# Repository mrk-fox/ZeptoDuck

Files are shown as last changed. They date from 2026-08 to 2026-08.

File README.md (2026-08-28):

<div align="center">
<h1>ZeptoDuck</h1><br>
The smallest "Rubber Ducky" in the world.
<br>

 

<br>

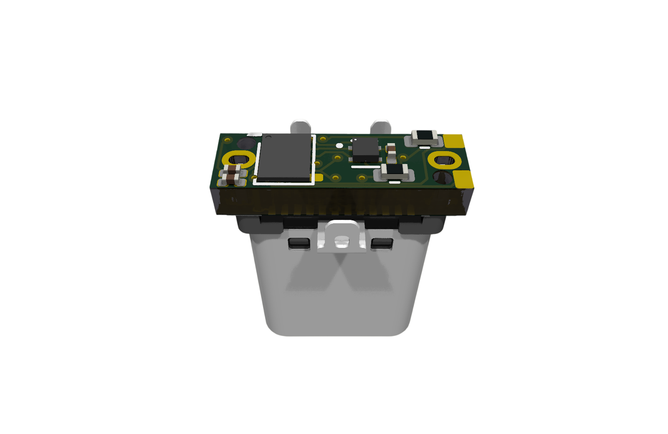
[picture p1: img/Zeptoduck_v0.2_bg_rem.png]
Flowers

</div>

# What is ZeptoDuck about?
In the world of rising digital vurneablility due to the effects of digitalization we are forced to develop tools to pentest the security structures we have developed and established over the years. One poular tool attackers use is the "Rubber Ducky". It is a broad term for a programmable HID execution device. The ZeptoDuck project, with the term "Zepto" coming from the greek word ζεπτο meaning one sextilionth is a electronics project to build such a device. The term "Zepto" was used to display the size of the ZeptoDuck being only about 10x3x15mm. This would be the world record for the smallest rubber ducky ever produced. 

# Features
ZeptoDuck covers a narrow spectre of features dur to its very specific usecase.

- ATSAMD11D14A-UUT as the main MCU
- Programmable via the SWD pads and the USB-C port with correct software.
- HID Input device capabilities.

# PCB and Schematics

The PCB itself is a minatuarized 2-Layer FR4 PCB with only a few components, most of them in very small formats.

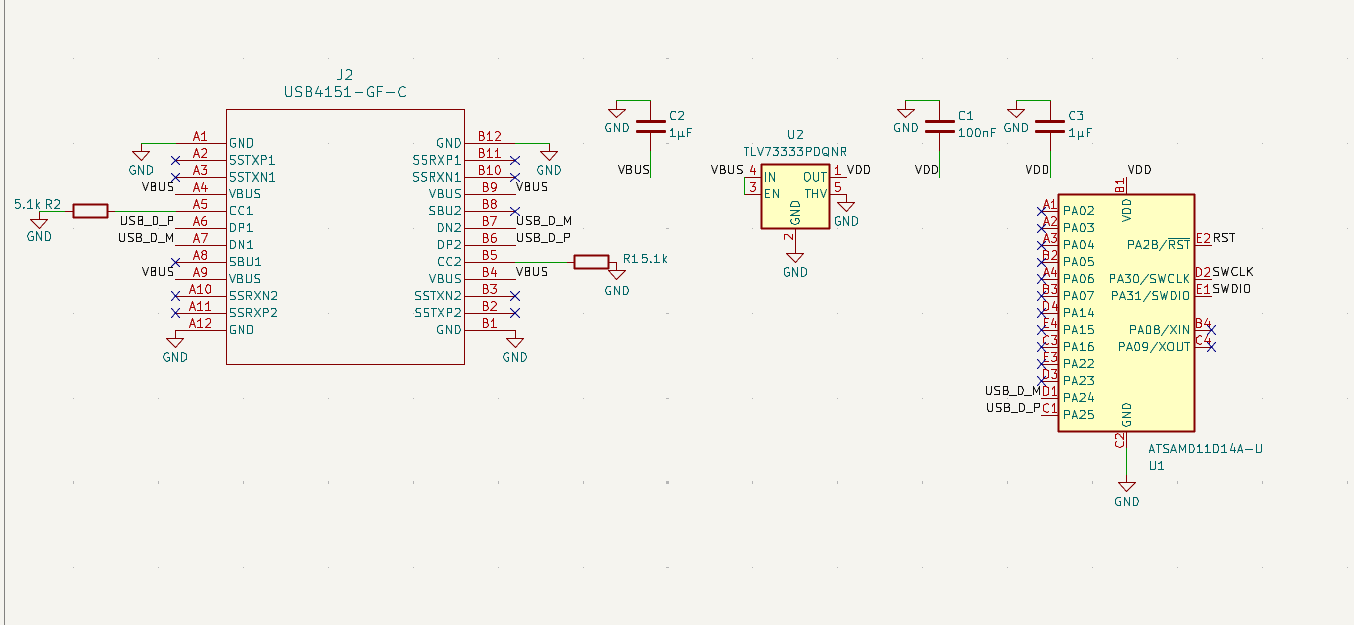
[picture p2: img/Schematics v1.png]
ZeptoDuck Schematics

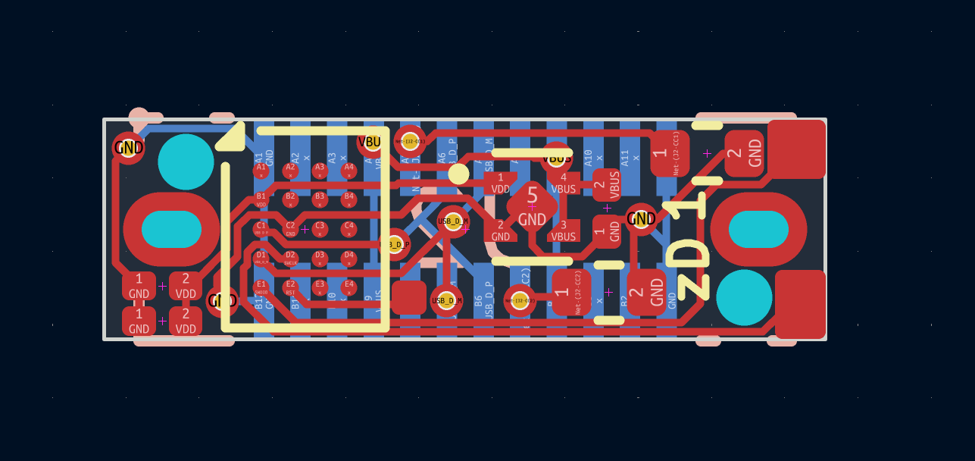
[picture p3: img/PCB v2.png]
ZeptoDuck PCB


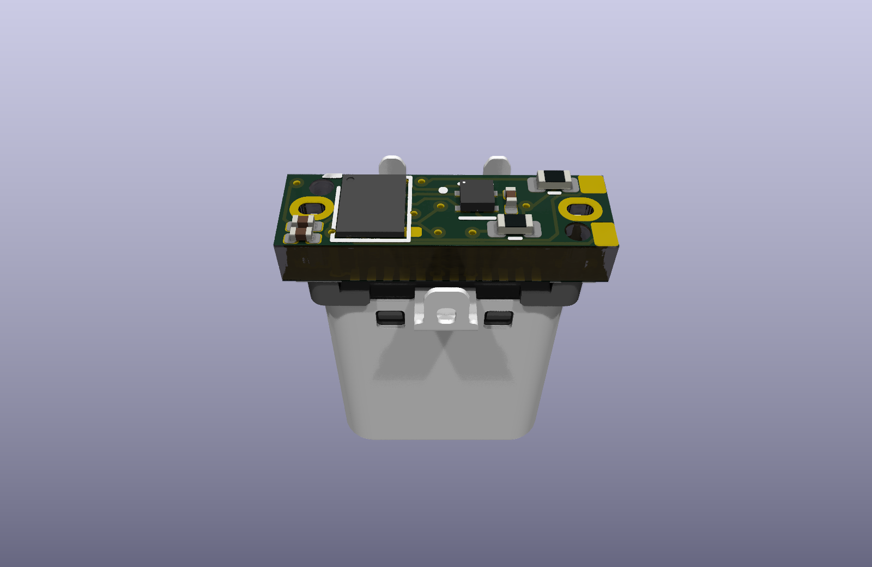
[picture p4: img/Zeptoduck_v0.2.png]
Zeptoduck Rendered

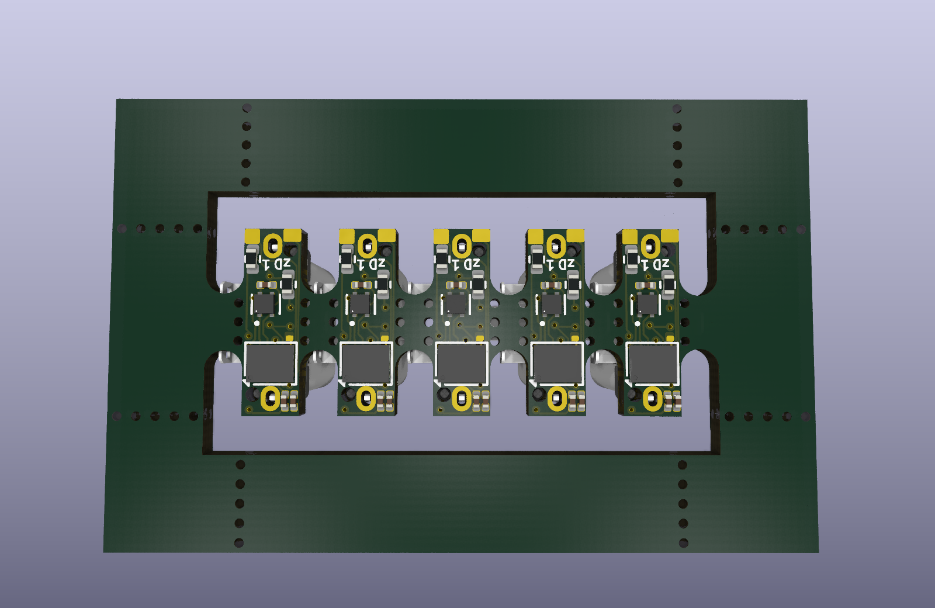
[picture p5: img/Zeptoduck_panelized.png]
Panelized ZeptoDuck Rendered


# Assembly and Flashing

1. Apply solder paste through the soldermask on all necessary components footprints
2. Place the components on the PCB
3. Use a hotplate to solder the components to the PCB
4. Cut off the additional holders for the USB-C port
5. Flip the PCB and hand-solder the USB-C port (The hard part)
6. Flash the PCB using any pogo pin assembly while applying 5V voltage through the USB-C port
7. Youre ready to hack!

# BOM

| id | Name | Qty | Price | |
|----|---|-----|---|---|
| 1  | PCB | 1 | 11.5$ | |
| 2  | ATSAMD11D14A-UUT | 10  | 16$ | |
| 3  | TLV73333PDQNR | 10  | 5$ | |
| 4  | WWE Shipping and Handling | 4 | 39$ | |
| x  | All other parts are in stock. | x | x | |
| x  | TOTAL | | 71.5$ | |

# Information for reviewers
28.08.2026: The parts are avalible via a custom agreement between me and Worldway electronics. This project required 22 hours in total to finish. Thanks for reviewing.

# Thanks
I generously thank Worldway Electronics for kindy agreeing on an MOQ relaxation. <br>
WWE Logo

Make sure to check out their website! 
worldwayelec.com

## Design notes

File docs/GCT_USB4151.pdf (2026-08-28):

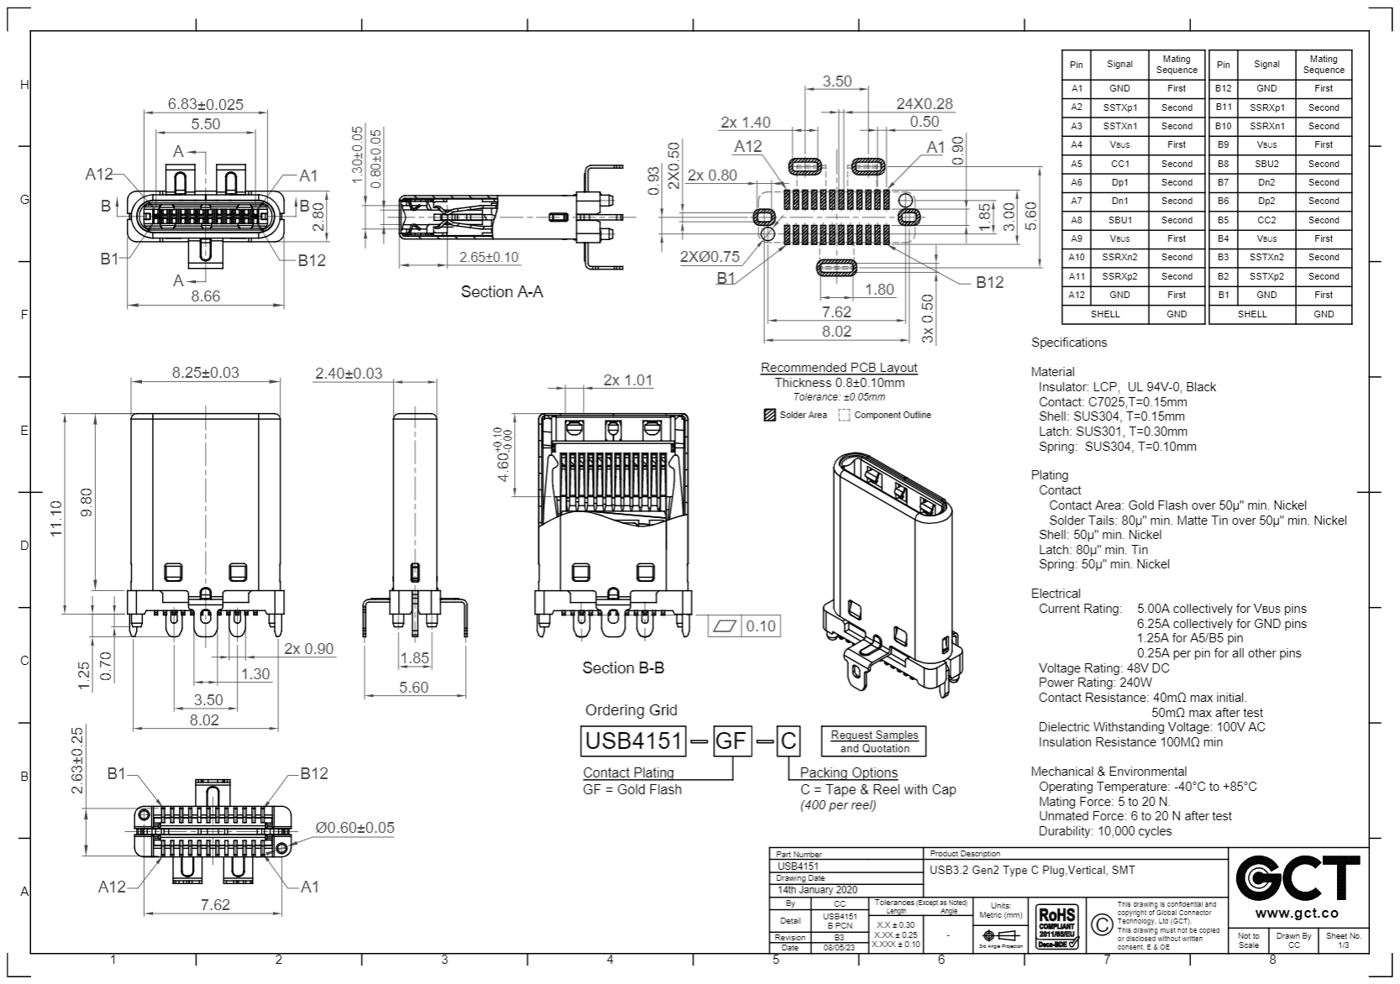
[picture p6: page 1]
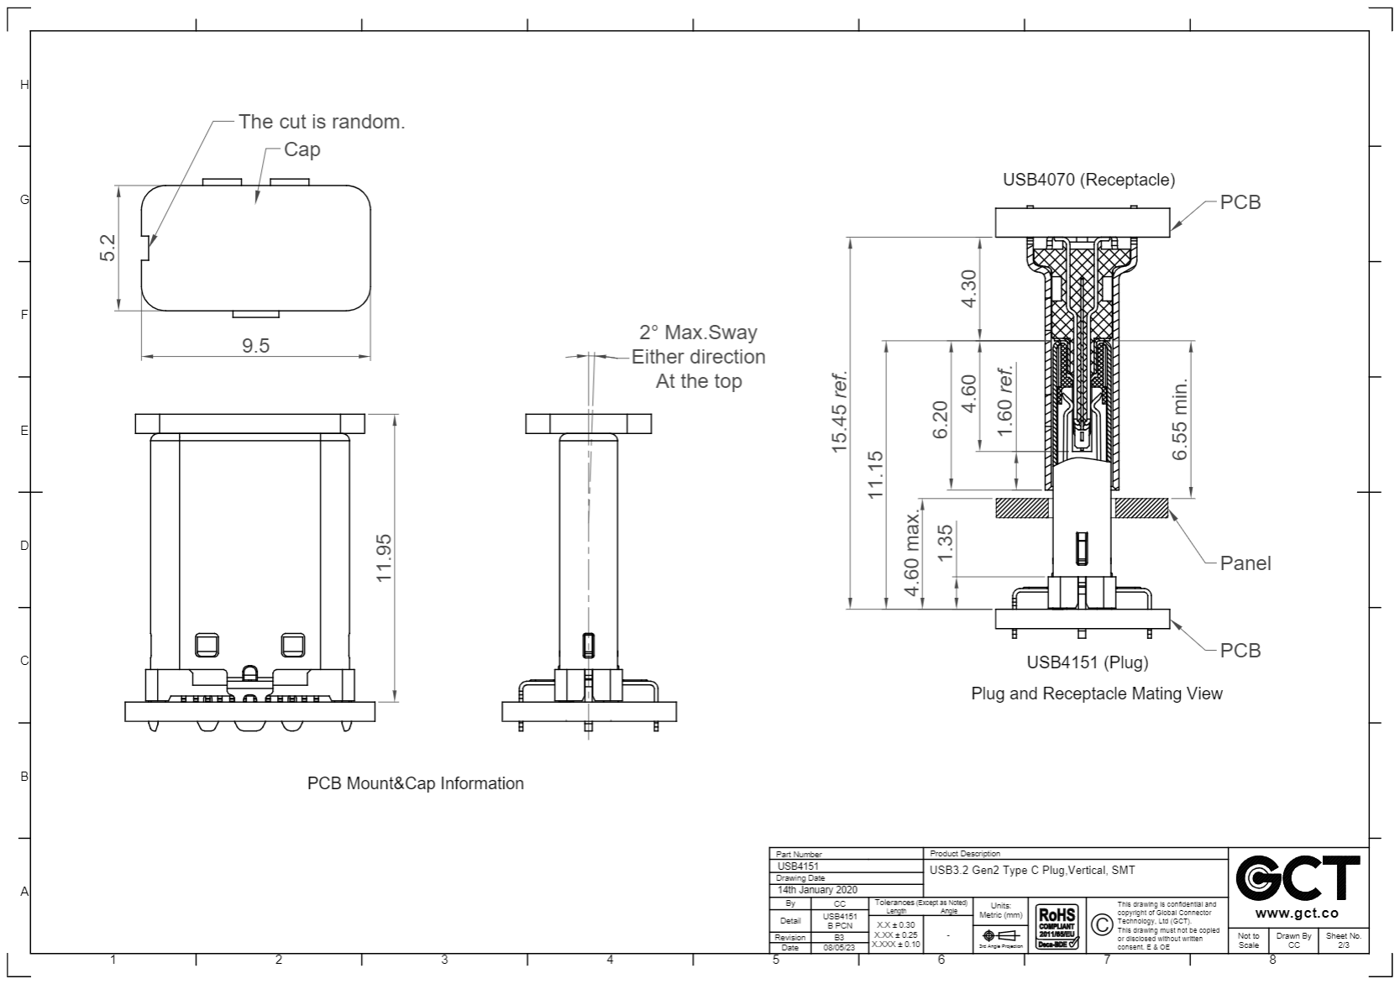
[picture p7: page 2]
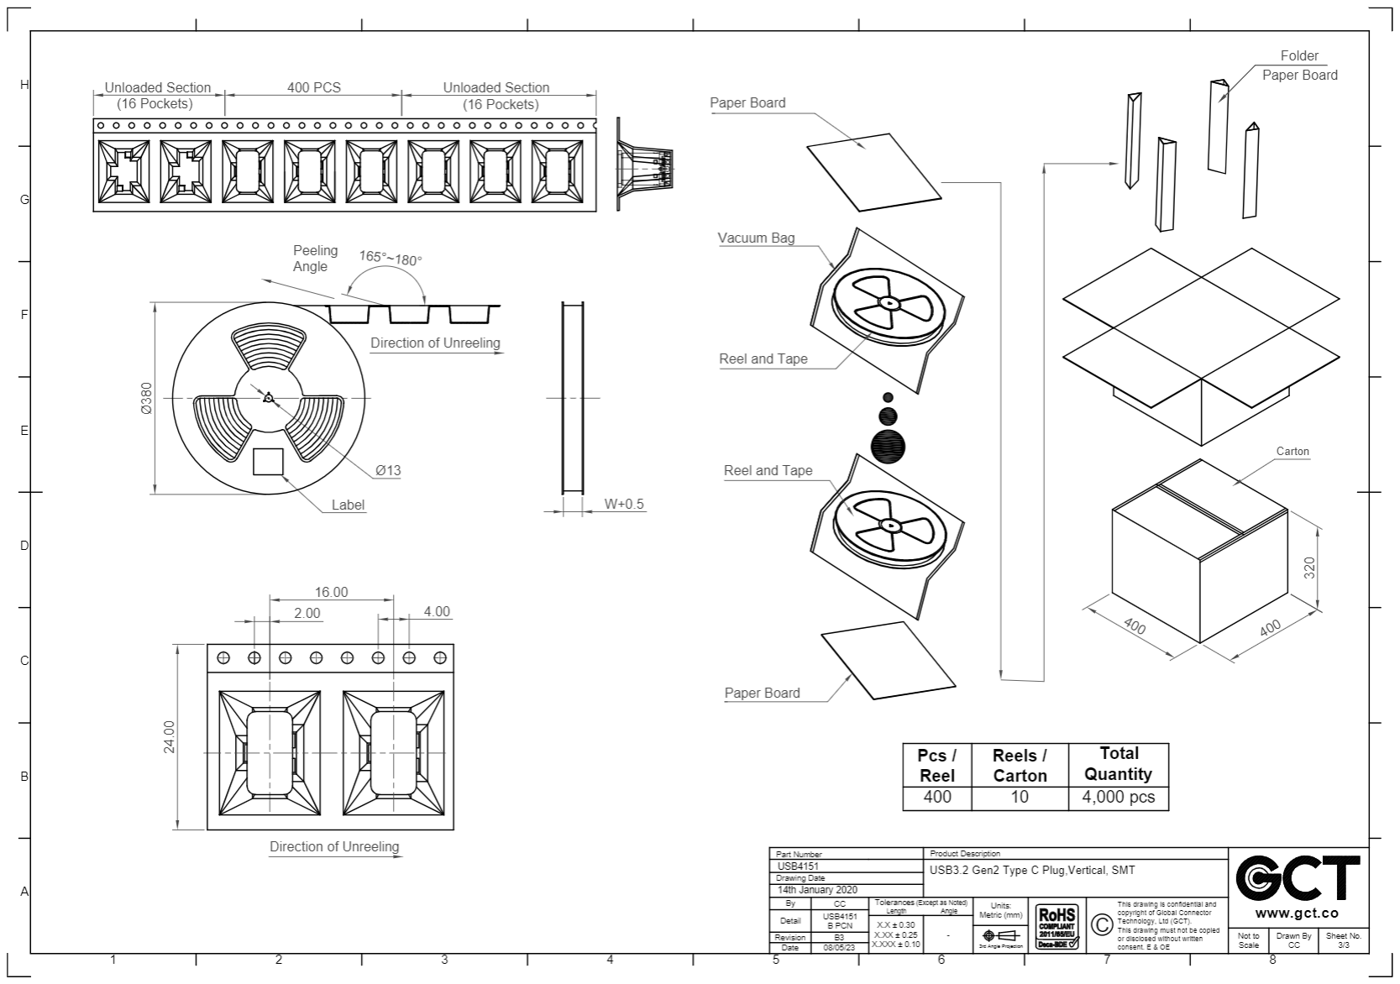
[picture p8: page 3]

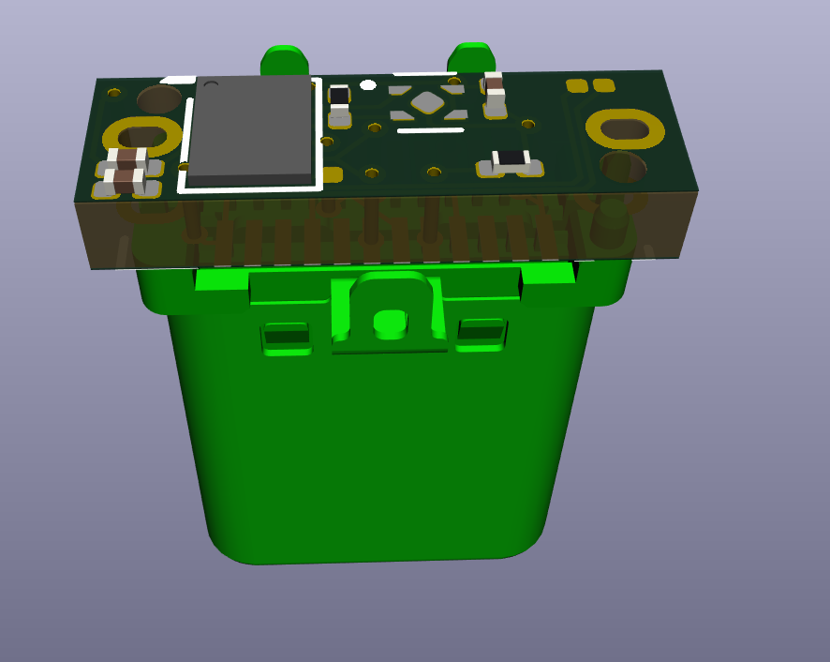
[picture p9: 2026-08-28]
img/3D view.png

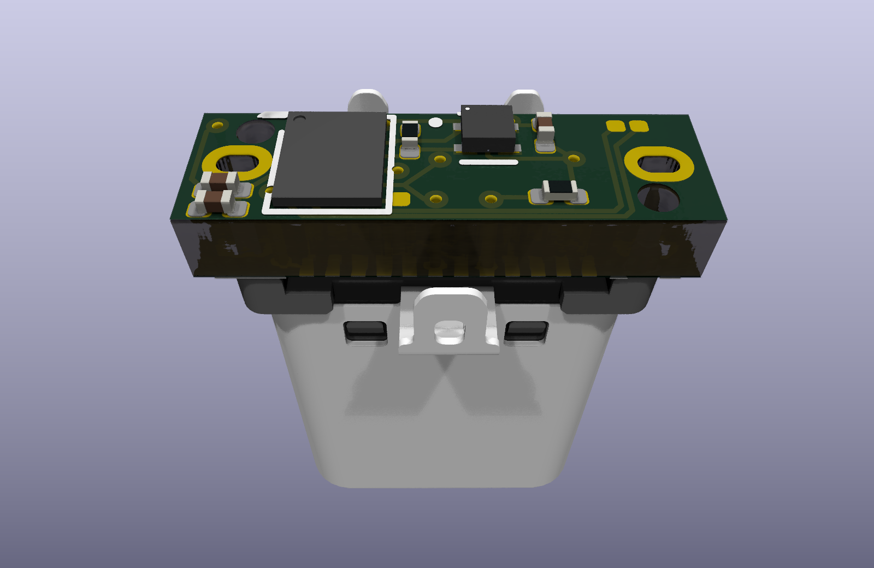
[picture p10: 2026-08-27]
img/Zeptoduck.png

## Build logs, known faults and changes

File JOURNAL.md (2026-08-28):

# Day 1 - Planning the project, finding components and completing the first schematic. Spent hours: 6

First of all: What is this project? This project aims to create the smallest "Rubber Ducky" in the world. The current record consists of a small PCB which is insertable into a "normal" USB port.

We define a "Rubber Ducky" as a programmable HID being able to fire a sequence of keystrokes to controll the PCB the Rubber Ducky is connected to.

So, as seen in the currently smallest Rubber Ducky given, the constraint comes actually not from the electronics components size but rather from the ports size. Therefore, going down the line we may look at an even smaller and newer port - The USB-C standart. The main
problem with the USB-C port is, that it is very small when it comes to the plugs dimension. While the female sockets are rather easy to work around, the male ones do only have 2 diffrent geometrical mounting options when described relative to the PCB: Horizontal and vertical.
While the horizontal mount is easier on the PCB's size, it compomises with the length, as the part of the USB-C plug being actually inserted into the port needs to be freed of any PCB below or beside it. The vertical mounting on the other hand is handier when it comes to the 
USB-C sizes, but rather complicted when you want to keep the PCB small. 

After some long concidertations I came to the conclusion that a vertically mounted PCB is more beneficial aiming at the "worlds smallest" element of the project, and the PCB's size constraint should rather be a challenge for me. 

So, the male PCB plug measures around 8x2mm width and height, and this should be concidered our PCB size goal when it comes to the component selection. 

### What to look for
We will probably need the following components:
1. An MCU with integrated USB pinout to avoid any additional parts
2. An voltage regulator to translate from the VBUS to the VCC of the chip
3. All the other 0201 components like decoupling caps
4. 5.1kOhm resistors for the CC1 and CC2 pins of the USB port.

And looking for the components I remembred a whole amazing class of chips made for such small projects: WLCSP. These are raw silicon dices with chips inside. And after some time on the Microchip website... I found what i needed. An ATSAMD11D14A-UUT resembling a wonderfu Cortex-0 MCU with
the very needed USB D+ and D- pins. The MCU works on 3.3V, as expected, so a drop down converter was needed. TI had a wonderful line of capacitatorless buck downs, the TLV733. And my hit was the TLV73333PDQNR in the proprietary TI 1x1mm package. A delicatess of a buck down.

Oh, and I nearly forgor the USBC port itself. The GCT Company (Global Connector Technology) has wonderful connectors worldwide! Amazing for my case. The one I need is the USB4151-GF-C. I will probably cut off the side-holders as they are tooo big for this project. 

### Schematics time

I love datasheets. The more I see them, the more I start understanding why compactification matters... BUT NOT TO THAT EXTENT. The SAMD11 Microchip WLCSP package I need had its USB pinout buried in the depths of its datasheet and until i fially understood the table, a lot of time
has passed. But I studied all datasheets and assembled by heart the follwing schematic:

ZeptoDuck Schematics

Puhhh... Long day. I think tomorrow is fially PCB time! Yay! 

# Day 2 - Creating the PCB and breaking and arm trying to fit everything in. 10 hours.

So, not much to tell today actually. After getting the necessary footprints, the fiddeling around the assembly began and I really struggled to fit everything in, comply with the JLCPCB manufacturing guidelines and the aquisition possibilities I have. The biggest problem was... When I suddenly notices THAT NEARLY NO ONE HAD THE MICROCHIPS I NEEDED IN STOCK. Aside from one company - Worldway electronics... With a goddamn MOQ (Minimum Order Quantity) of 500 pcs... I wrote them an E-Mail asking for a MOQ relaxation for a poor student trying to break some world record. Lets see what they answer. The second problem is, that nearly no 0201 5.1kOhm resistors are anywhere in stock at an acceptable price-to-MOQ ratio. Well, i switches to 0402... and fitting them was.. phuh. The main problem was also in my head. I really didnt want to switch to a 4-Layer-PCB as this would just increase the VIA amount and placing a VIA anywhere is a huge compomise. I did it only when needed. I also sadly couldnt place any vias in between the MCU's pins due to the spacing colliding with JLCPCB's manufacturing constraints. BUT! Throgh herous effort I managed to route all that and pass ERC and DRC with flying colors... In nothing but 10 hours of pure swearing. One thing I learned today was, that JLCPCB is really lame. Their constraints are really constraint constrainting me in my concentration on size constraint compromized placement. Here, the finished PCB:
ZeptoDuck PCB

# Day 3 - Finishing Panelization, Fimrware and moving files around for the ship. 5 hours.

Okay, as JLCPCB would struggle a lot manufacturing my 8x2mm PCB's, I'll help them a bit by creating a panel with 5 of them. This was very interesting as KiKit, the paneöization automator refused to ooperate on the behalf of such a small chip. I also wrote a lot of code. SAMD11 is a chip I know so it was faster than the first time, however, i needed a lot of time to even figure out HOW to make a HID device ot of a small and cute chip. I also learned a lot new about USB protocolls. Currently the firmware just configures itself as a keyboard on fireup and types Win+R and then notpad and stays idle until rebootet. Thats all currently. Here a pic of the finished panelization and the rendered ZeptoDuck.

ZeptoDuck Panelized PCB

And also... WORLDWAY ELECTRONICS ANSWERED! They agreed to support me and agreed to give me all the things necessary for 65 incl. shipping! 
All this took 5 hours

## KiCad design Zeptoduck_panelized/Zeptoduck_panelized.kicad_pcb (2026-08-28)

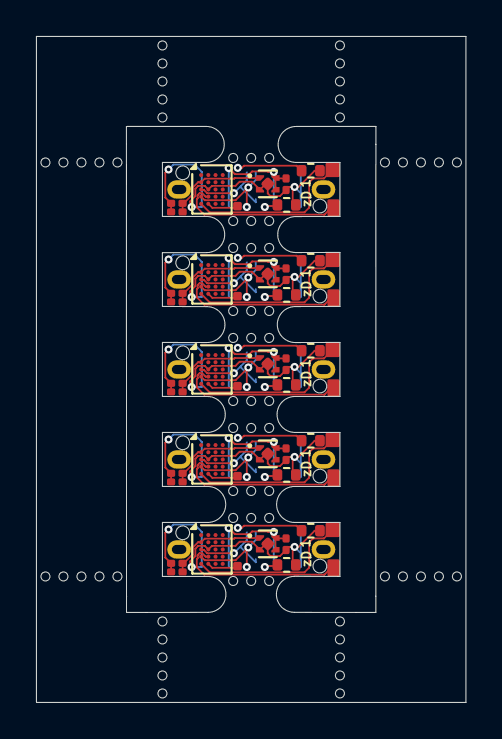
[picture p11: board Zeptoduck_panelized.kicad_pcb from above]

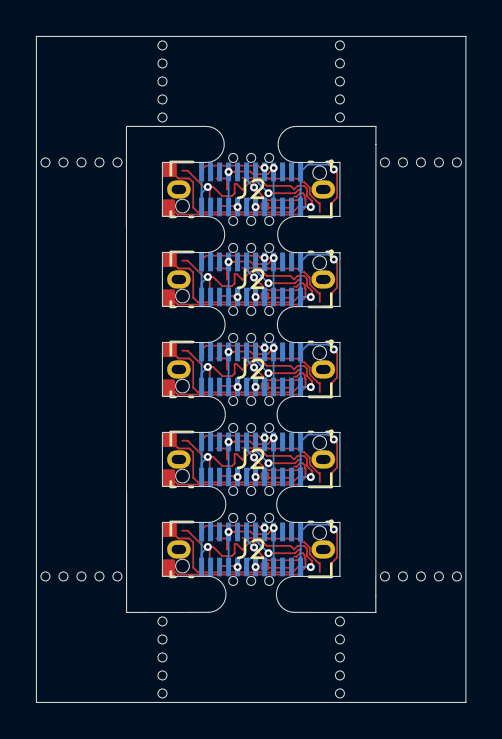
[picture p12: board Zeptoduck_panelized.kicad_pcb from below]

Board: 2 copper layers, 23.9 x 37.0 mm, 110 parts (5 on the bottom side), 35 nets.

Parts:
C1, C1#2, C1#3, C1#4, C1#5: 100nF; C_0201_0603Metric
C2, C2#2, C2#3, C2#4, C2#5, C3, C3#2, C3#3, C3#4, C3#5: 1µF; C_0201_0603Metric
J2, J2#2, J2#3, J2#4, J2#5: USB4151-GF-C; USB4151-GF-C_GCT_LESS
KiKit_MB_1_2, KiKit_MB_1_3, KiKit_MB_1_4, KiKit_MB_2_2, KiKit_MB_2_3, KiKit_MB_2_4, KiKit_MB_3_2, KiKit_MB_3_3, KiKit_MB_3_4, KiKit_MB_4_2, KiKit_MB_4_3, KiKit_MB_4_4, KiKit_MB_5_2, KiKit_MB_5_3, KiKit_MB_5_4, KiKit_MB_6_2, KiKit_MB_6_3, KiKit_MB_6_4, KiKit_MB_7_2, KiKit_MB_7_3, KiKit_MB_7_4, KiKit_MB_8_2, KiKit_MB_8_3, KiKit_MB_8_4, KiKit_MB_9_2, KiKit_MB_9_3, KiKit_MB_9_4, KiKit_MB_10_2, KiKit_MB_10_3, KiKit_MB_10_4, KiKit_MB_11_2, KiKit_MB_11_3, KiKit_MB_11_4, KiKit_MB_11_5, KiKit_MB_11_6, KiKit_MB_12_2, KiKit_MB_12_3, KiKit_MB_12_4, KiKit_MB_12_5, KiKit_MB_12_6, KiKit_MB_13_2, KiKit_MB_13_3, KiKit_MB_13_4, KiKit_MB_13_5, KiKit_MB_13_6, KiKit_MB_14_2, KiKit_MB_14_3, KiKit_MB_14_4, KiKit_MB_14_5, KiKit_MB_14_6, KiKit_MB_15_2, KiKit_MB_15_3, KiKit_MB_15_4, KiKit_MB_15_5, KiKit_MB_15_6, KiKit_MB_16_2, KiKit_MB_16_3, KiKit_MB_16_4, KiKit_MB_16_5, KiKit_MB_16_6, KiKit_MB_17_2, KiKit_MB_17_3, KiKit_MB_17_4, KiKit_MB_17_5, KiKit_MB_17_6, KiKit_MB_18_2, KiKit_MB_18_3, KiKit_MB_18_4, KiKit_MB_18_5, KiKit_MB_18_6: NPTH
R1, R1#2, R1#3, R1#4, R1#5, R2, R2#2, R2#3, R2#4, R2#5: 5.1k; R_0402_1005Metric
U1, U1#2, U1#3, U1#4, U1#5: ATSAMD11D14A-U; WLCSP-20_1.934x2.434mm_Layout4x5_P0.4mm
U2, U2#2, U2#3, U2#4, U2#5: TLV73333PDQNR; Texas_X2SON-4_1x1mm_P0.65mm

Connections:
Board_0-/USB_D_M: J2#3.A7 (DN1), J2#3.B7 (DN2), U1#5.D1 (PA24)
Board_0-/USB_D_P: J2#3.A6 (DP1), J2#3.B6 (DP2), U1#5.C1 (PA25)
Board_0-/VBUS: C2#2.2, J2#3.A4 (VBUS), J2#3.A9 (VBUS), J2#3.B4 (VBUS), J2#3.B9 (VBUS), U2#3.3 (EN), U2#3.4 (IN)
Board_0-/VDD: C1#4.2, C3#4.2, U1#5.B1 (VDD), U2#3.1 (OUT)
Board_0-GND: C1#4.1, C2#2.1, C3#4.1, J2#3.A1 (GND), J2#3.A12 (GND), J2#3.B1 (GND), J2#3.B12 (GND), R1#4.2, R2#3.2, U1#5.C2 (GND), U2#3.2 (GND), U2#3.5 (THV)
Board_0-Net-(J2-CC1): J2#3.A5 (CC1), R2#3.1
Board_0-Net-(J2-CC2): J2#3.B5 (CC2), R1#4.1
Board_1-/USB_D_M: J2#4.A7 (DN1), J2#4.B7 (DN2), U1#4.D1 (PA24)
Board_1-/USB_D_P: J2#4.A6 (DP1), J2#4.B6 (DP2), U1#4.C1 (PA25)
Board_1-/VBUS: C2#3.2, J2#4.A4 (VBUS), J2#4.A9 (VBUS), J2#4.B4 (VBUS), J2#4.B9 (VBUS), U2#4.3 (EN), U2#4.4 (IN)
Board_1-/VDD: C1#5.2, C3#2.2, U1#4.B1 (VDD), U2#4.1 (OUT)
Board_1-GND: C1#5.1, C2#3.1, C3#2.1, J2#4.A1 (GND), J2#4.A12 (GND), J2#4.B1 (GND), J2#4.B12 (GND), R1#2.2, R2#5.2, U1#4.C2 (GND), U2#4.2 (GND), U2#4.5 (THV)
Board_1-Net-(J2-CC1): J2#4.A5 (CC1), R2#5.1
Board_1-Net-(J2-CC2): J2#4.B5 (CC2), R1#2.1
Board_2-/USB_D_M: J2#2.A7 (DN1), J2#2.B7 (DN2), U1#3.D1 (PA24)
Board_2-/USB_D_P: J2#2.A6 (DP1), J2#2.B6 (DP2), U1#3.C1 (PA25)
Board_2-/VBUS: C2#5.2, J2#2.A4 (VBUS), J2#2.A9 (VBUS), J2#2.B4 (VBUS), J2#2.B9 (VBUS), U2#5.3 (EN), U2#5.4 (IN)
Board_2-/VDD: C1#2.2, C3.2, U1#3.B1 (VDD), U2#5.1 (OUT)
Board_2-GND: C1#2.1, C2#5.1, C3.1, J2#2.A1 (GND), J2#2.A12 (GND), J2#2.B1 (GND), J2#2.B12 (GND), R1.2, R2.2, U1#3.C2 (GND), U2#5.2 (GND), U2#5.5 (THV)
Board_2-Net-(J2-CC1): J2#2.A5 (CC1), R2.1
Board_2-Net-(J2-CC2): J2#2.B5 (CC2), R1.1
Board_3-/USB_D_M: J2#5.A7 (DN1), J2#5.B7 (DN2), U1#2.D1 (PA24)
Board_3-/USB_D_P: J2#5.A6 (DP1), J2#5.B6 (DP2), U1#2.C1 (PA25)
Board_3-/VBUS: C2#4.2, J2#5.A4 (VBUS), J2#5.A9 (VBUS), J2#5.B4 (VBUS), J2#5.B9 (VBUS), U2.3 (EN), U2.4 (IN)
Board_3-/VDD: C1.2, C3#5.2, U1#2.B1 (VDD), U2.1 (OUT)
Board_3-GND: C1.1, C2#4.1, C3#5.1, J2#5.A1 (GND), J2#5.A12 (GND), J2#5.B1 (GND), J2#5.B12 (GND), R1#5.2, R2#4.2, U1#2.C2 (GND), U2.2 (GND), U2.5 (THV)
Board_3-Net-(J2-CC1): J2#5.A5 (CC1), R2#4.1
Board_3-Net-(J2-CC2): J2#5.B5 (CC2), R1#5.1
Board_4-/USB_D_M: J2.A7 (DN1), J2.B7 (DN2), U1.D1 (PA24)
Board_4-/USB_D_P: J2.A6 (DP1), J2.B6 (DP2), U1.C1 (PA25)
Board_4-/VBUS: C2.2, J2.A4 (VBUS), J2.A9 (VBUS), J2.B4 (VBUS), J2.B9 (VBUS), U2#2.3 (EN), U2#2.4 (IN)
Board_4-/VDD: C1#3.2, C3#3.2, U1.B1 (VDD), U2#2.1 (OUT)
Board_4-GND: C1#3.1, C2.1, C3#3.1, J2.A1 (GND), J2.A12 (GND), J2.B1 (GND), J2.B12 (GND), R1#3.2, R2#2.2, U1.C2 (GND), U2#2.2 (GND), U2#2.5 (THV)
Board_4-Net-(J2-CC1): J2.A5 (CC1), R2#2.1
Board_4-Net-(J2-CC2): J2.B5 (CC2), R1#3.1

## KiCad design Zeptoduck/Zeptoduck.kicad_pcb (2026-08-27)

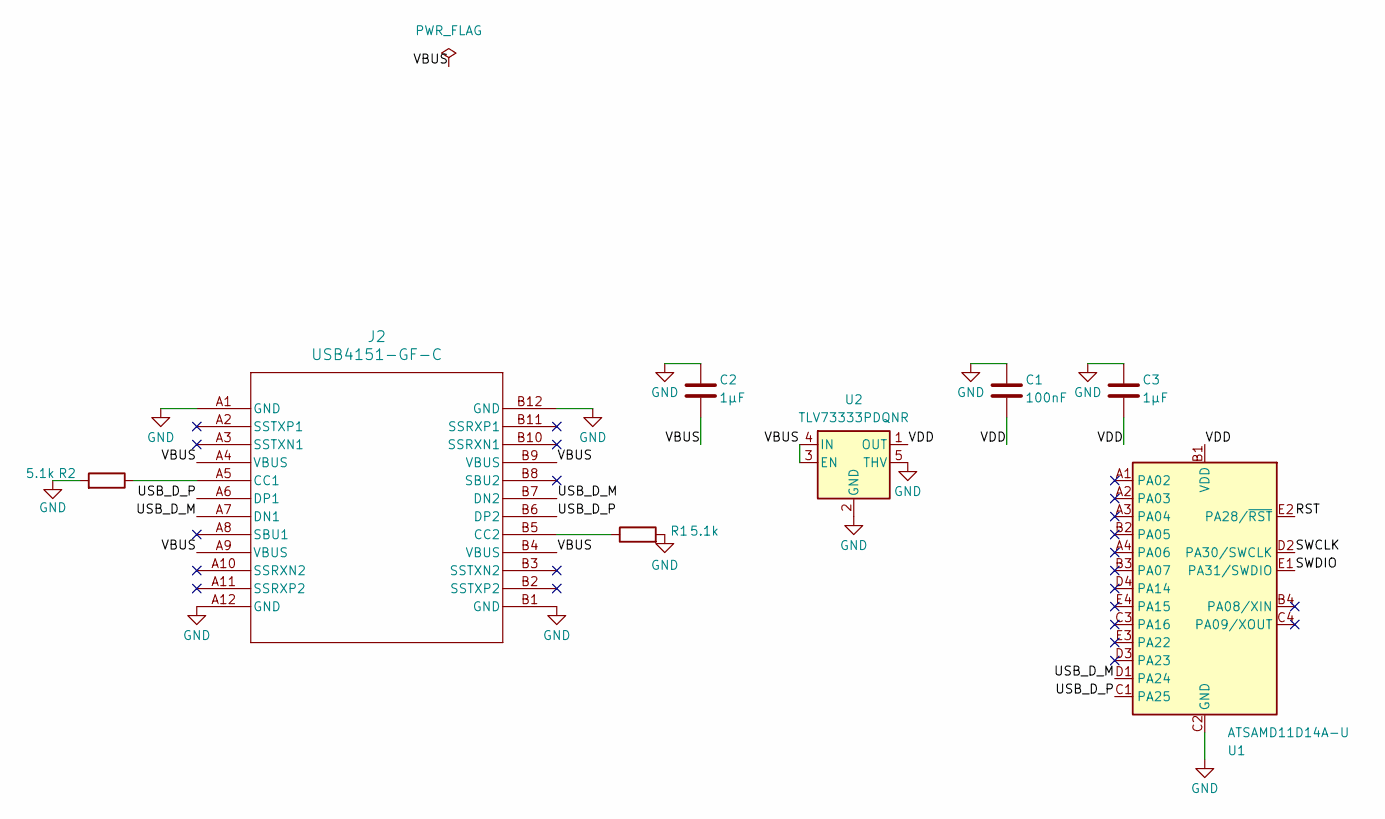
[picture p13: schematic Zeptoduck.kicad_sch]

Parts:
C1: 100nF; C_0201_0603Metric
C2, C3: 1µF; C_0201_0603Metric
J2: USB4151-GF-C; USB4151-GF-C_GCT_LESS
R1, R2: 5.1k; R_0402_1005Metric
U1: ATSAMD11D14A-U; WLCSP-20_1.934x2.434mm_Layout4x5_P0.4mm
U2: TLV73333PDQNR; Texas_X2SON-4_1x1mm_P0.65mm

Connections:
/RST: U1.E2 (PA28/~RST)
/SWCLK: U1.D2 (PA30/SWCLK)
/SWDIO: U1.E1 (PA31/SWDIO)
/USB_D_M: J2.A7 (DN1), J2.B7 (DN2), U1.D1 (PA24)
/USB_D_P: J2.A6 (DP1), J2.B6 (DP2), U1.C1 (PA25)
/VBUS: C2.2, J2.A4 (VBUS), J2.A9 (VBUS), J2.B4 (VBUS), J2.B9 (VBUS), U2.3 (EN), U2.4 (IN)
/VDD: C1.2, C3.2, U1.B1 (VDD), U2.1 (OUT)
GND: C1.1, C2.1, C3.1, J2.A1 (GND), J2.A12 (GND), J2.B1 (GND), J2.B12 (GND), R1.2, R2.2, U1.C2 (GND), U2.2 (GND), U2.5 (THV)
unnamed: J2.A5 (CC1), R2.1
unnamed: J2.B5 (CC2), R1.1

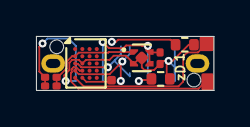
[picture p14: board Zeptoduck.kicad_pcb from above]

Board: 2 copper layers, 9.9 x 3.0 mm, 8 parts (1 on the bottom side), 7 nets.

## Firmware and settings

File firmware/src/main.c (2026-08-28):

#include <stdint.h>
#include <stddef.h>

#define REG8(a)   (*(volatile uint8_t  *)(a))
#define REG16(a)  (*(volatile uint16_t *)(a))
#define REG32(a)  (*(volatile uint32_t *)(a))

#define NVMCTRL_CTRLB       REG32(0x41004004u)

#define PM_AHBMASK          REG32(0x40000414u)
#define PM_APBBMASK         REG32(0x4000041Cu)
#define PM_AHBMASK_USB      (1u << 6)
#define PM_APBBMASK_USB     (1u << 5)

#define SYSCTRL_INTFLAG     REG32(0x4000080Cu)
#define SYSCTRL_DFLLCTRL    REG16(0x40000824u)
#define SYSCTRL_DFLLVAL     REG32(0x40000828u)
#define SYSCTRL_DFLLMUL     REG32(0x4000082Cu)
#define SYSCTRL_INTFLAG_DFLLRDY (1u << 4)
#define DFLLCTRL_ENABLE     (1u << 1)
#define DFLLCTRL_MODE       (1u << 2)
#define DFLLCTRL_USBCRM     (1u << 5)
#define DFLLCTRL_CCDIS      (1u << 8)

#define GCLK_CTRL           REG8 (0x40000C00u)
#define GCLK_STATUS         REG8 (0x40000C01u)
#define GCLK_CLKCTRL        REG16(0x40000C02u)
#define GCLK_GENCTRL        REG32(0x40000C04u)
#define GCLK_GENDIV         REG32(0x40000C08u)
#define GCLK_STATUS_SYNCBUSY (1u << 7)
#define GCLK_SRC_DFLL48M    7u
#define GCLK_ID_USB         0x06u

#define PORT_PINCFG(n)      REG8(0x41004440u + (n))
#define PORT_PMUX(n)        REG8(0x41004430u + (n))
#define PINCFG_PMUXEN       (1u << 0)
#define PMUX_FUNC_G         6u

#define USB_BASE           0x41005000u
#define USB_CTRLA          REG8 (USB_BASE + 0x00u)
#define USB_SYNCBUSY       REG8 (USB_BASE + 0x02u)
#define USB_QOSCTRL        REG8 (USB_BASE + 0x03u)
#define USB_CTRLB          REG16(USB_BASE + 0x08u)
#define USB_DADD           REG8 (USB_BASE + 0x0Au)
#define USB_INTFLAG        REG16(USB_BASE + 0x1Cu)
#define USB_DESCADD        REG32(USB_BASE + 0x24u)
#define USB_PADCAL         REG16(USB_BASE + 0x28u)

#define USB_CTRLA_SWRST    (1u << 0)
#define USB_CTRLA_ENABLE   (1u << 1)
#define USB_CTRLA_RUNSTDBY (1u << 2)
#define USB_CTRLA_MODE_DEV (0u << 7)
#define USB_SYNCBUSY_SWRST (1u << 0)
#define USB_SYNCBUSY_ENABLE (1u << 1)
#define USB_CTRLB_DETACH   (1u << 0)
#define USB_INTFLAG_EORST  (1u << 3)

#define USB_EP(n)          (USB_BASE + 0x100u + (n) * 0x20u)
#define USB_EPCFG(n)       REG8(USB_EP(n) + 0x00u)
#define USB_EPSTATUSCLR(n) REG8(USB_EP(n) + 0x04u)
#define USB_EPSTATUSSET(n) REG8(USB_EP(n) + 0x05u)
#define USB_EPSTATUS(n)    REG8(USB_EP(n) + 0x06u)
#define USB_EPINTFLAG(n)   REG8(USB_EP(n) + 0x07u)

#define EPCFG_TYPE0(v)     ((v) << 0)
#define EPCFG_TYPE1(v)     ((v) << 4)
#define EPTYPE_CONTROL     1u
#define EPTYPE_INT_IN      4u

#define EPINT_TRCPT0       (1u << 0)
#define EPINT_TRCPT1       (1u << 1)
#define EPINT_RXSTP        (1u << 4)
#define EPSTATUS_DTGLIN    (1u << 1)
#define EPSTATUS_STALLRQ0  (1u << 4)
#define EPSTATUS_STALLRQ1  (1u << 5)
#define EPSTATUS_BK0RDY    (1u << 6)
#define EPSTATUS_BK1RDY    (1u << 7)

#define PCKSIZE_SIZE_8     (0u << 28)
#define PCKSIZE_SIZE_64    (3u << 28)
#define PCKSIZE_IN(len)    ((uint32_t)(len) & 0x3FFFu)
#define PCKSIZE_OUT(cap)   ((uint32_t)(cap) << 14)

#define SYST_CSR           REG32(0xE000E010u)
#define SYST_RVR           REG32(0xE000E014u)
#define SYST_CVR           REG32(0xE000E018u)
#define SYST_CSR_ENABLE    (1u << 0)
#define SYST_CSR_CLKCORE   (1u << 2)
#define SYST_CSR_COUNTFLAG (1u << 16)

#define NVM_CAL_WORD1      REG32(0x00806024u)

void *memset(void *d, int c, size_t n)
{
	uint8_t *p = d;
	while (n--)
		*p++ = (uint8_t)c;
	return d;
}

void *memcpy(void *d, const void *s, size_t n)
{
	uint8_t *a = d;
	const uint8_t *b = s;
	while (n--)
		*a++ = *b++;
	return d;
}

#define VID  0x1209
#define PID  0x0001

static const uint8_t dev_desc[18] = {
	18, 0x01,
	0x00, 0x02,
	0x00, 0x00, 0x00,
	64,
	(VID & 0xFF), (VID >> 8),
	(PID & 0xFF), (PID >> 8),
	0x00, 0x01,
	1, 2, 0,
	1,
};

#define REPORT_DESC_LEN 63
static const uint8_t report_desc[REPORT_DESC_LEN] = {
	0x05, 0x01,
	0x09, 0x06,
	0xA1, 0x01,
	0x05, 0x07,
	0x19, 0xE0,
	0x29, 0xE7,
	0x15, 0x00,
	0x25, 0x01,
	0x75, 0x01,
	0x95, 0x08,
	0x81, 0x02,
	0x95, 0x01,
	0x75, 0x08,
	0x81, 0x03,
	0x95, 0x05,
	0x75, 0x01,
	0x05, 0x08,
	0x19, 0x01,
	0x29, 0x05,
	0x91, 0x02,
	0x95, 0x01,
	0x75, 0x03,
	0x91, 0x03,
	0x95, 0x06,
	0x75, 0x08,
	0x15, 0x00,
	0x25, 0x65,
	0x05, 0x07,
	0x19, 0x00,
	0x29, 0x65,
	0x81, 0x00,
	0xC0,
};

#define CFG_DESC_LEN 34
static const uint8_t cfg_desc[CFG_DESC_LEN] = {
	9, 0x02, CFG_DESC_LEN, 0x00, 1, 1, 0, 0x80, 50,
	9, 0x04, 0, 0, 1, 0x03, 0x01, 0x01, 0,
	9, 0x21, 0x11, 0x01, 0x00, 1, 0x22, REPORT_DESC_LEN, 0x00,
	7, 0x05, 0x81, 0x03, 8, 0x00, 5,
};

typedef struct {
	uint32_t ADDR;
	uint32_t PCKSIZE;
	uint16_t EXTREG;
	uint8_t  STATUS_BK;
	uint8_t  _pad0;
	uint32_t _pad1;
} usb_bank_t;

typedef struct { usb_bank_t bank[2]; } usb_ep_t;

typedef struct {
	uint8_t  bmRequestType;
	uint8_t  bRequest;
	uint16_t wValue;
	uint16_t wIndex;
	uint16_t wLength;
} setup_t;

static volatile usb_ep_t ep_desc[2] __attribute__((aligned(4)));
static uint8_t ep0_out[64] __attribute__((aligned(4)));
static uint8_t ep0_in[64]  __attribute__((aligned(4)));
static uint8_t ep1_in[8]   __attribute__((aligned(4)));
static setup_t setup;
static volatile uint8_t usb_config_value;
static volatile uint8_t usb_configured;

static void clock_init(void)
{
	NVMCTRL_CTRLB = (NVMCTRL_CTRLB & ~(0xFu << 1)) | (1u << 1);

	PM_AHBMASK  |= PM_AHBMASK_USB;
	PM_APBBMASK |= PM_APBBMASK_USB;

	SYSCTRL_DFLLCTRL = DFLLCTRL_ENABLE;
	while (!(SYSCTRL_INTFLAG & SYSCTRL_INTFLAG_DFLLRDY))
		;

	SYSCTRL_DFLLVAL = ((NVM_CAL_WORD1 >> 26) & 0x3Fu) << 10;

	SYSCTRL_DFLLMUL = (6u << 26) | (0x3Fu << 16) | 48000u;

	SYSCTRL_DFLLCTRL = DFLLCTRL_ENABLE | DFLLCTRL_MODE |
	                   DFLLCTRL_USBCRM | DFLLCTRL_CCDIS;
	while (!(SYSCTRL_INTFLAG & SYSCTRL_INTFLAG_DFLLRDY))
		;

	GCLK_GENDIV = 0u;
	while (GCLK_STATUS & GCLK_STATUS_SYNCBUSY)
		;
	GCLK_GENCTRL = 0u | (GCLK_SRC_DFLL48M << 8) | (1u << 16) | (1u << 17);
	while (GCLK_STATUS & GCLK_STATUS_SYNCBUSY)
		;

	GCLK_CLKCTRL = GCLK_ID_USB | (0u << 8) | (1u << 14);
	while (GCLK_STATUS & GCLK_STATUS_SYNCBUSY)
		;
}

static void usb_task(void);

static void systick_init(void)
{
	SYST_RVR = 48000u - 1u;
	SYST_CVR = 0u;
	SYST_CSR = SYST_CSR_ENABLE | SYST_CSR_CLKCORE;
}

static void delay_ms(uint32_t ms)
{
	while (ms--) {
		while (!(SYST_CSR & SYST_CSR_COUNTFLAG))
			usb_task();
	}
}

static void ep0_init(void)
{
	USB_EPCFG(0) = EPCFG_TYPE0(EPTYPE_CONTROL) | EPCFG_TYPE1(EPTYPE_CONTROL);
	USB_EPINTFLAG(0) = 0xFF;

	ep_desc[0].bank[0].ADDR    = (uint32_t)ep0_out;
	ep_desc[0].bank[0].PCKSIZE = PCKSIZE_SIZE_64 | PCKSIZE_OUT(64);
	ep_desc[0].bank[1].ADDR    = (uint32_t)ep0_in;
	ep_desc[0].bank[1].PCKSIZE = PCKSIZE_SIZE_64;

	USB_EPSTATUSCLR(0) = EPSTATUS_BK0RDY;
	USB_EPSTATUSCLR(0) = EPSTATUS_BK1RDY;
}

static void ep1_init(void)
{
	USB_EPCFG(1) = EPCFG_TYPE1(EPTYPE_INT_IN);
	USB_EPINTFLAG(1) = 0xFF;
	USB_EPSTATUSCLR(1) = EPSTATUS_BK1RDY | EPSTATUS_DTGLIN |
	                     EPSTATUS_STALLRQ0 | EPSTATUS_STALLRQ1;
	ep_desc[1].bank[1].ADDR    = (uint32_t)ep1_in;
	ep_desc[1].bank[1].PCKSIZE = PCKSIZE_SIZE_8;
}

static void ctrl_stall(void)
{
	USB_EPSTATUSSET(0) = EPSTATUS_STALLRQ0 | EPSTATUS_STALLRQ1;
}

static void ctrl_send(const void *data, uint32_t len)
{
	if (len > setup.wLength)
		len = setup.wLength;
	memcpy(ep0_in, data, len);
	ep_desc[0].bank[1].PCKSIZE = PCKSIZE_SIZE_64 | PCKSIZE_IN(len);
	USB_EPINTFLAG(0) = EPINT_TRCPT1;
	USB_EPSTATUSSET(0) = EPSTATUS_BK1RDY;
}

static void ctrl_zlp(void)
{
	ep_desc[0].bank[1].PCKSIZE = PCKSIZE_SIZE_64 | PCKSIZE_IN(0);
	USB_EPINTFLAG(0) = EPINT_TRCPT1;
	USB_EPSTATUSSET(0) = EPSTATUS_BK1RDY;
}

static void send_string(uint8_t idx)
{
	uint8_t *b = ep0_in;

	if (idx == 0) {
		b[0] = 4; b[1] = 0x03; b[2] = 0x09; b[3] = 0x04;
		ctrl_send(b, 4);
		return;
	}

	const char *s;
	if (idx == 1)
		s = "ZeptoDuck";
	else if (idx == 2)
		s = "ZeptoDuck HID";
	else {
		ctrl_stall();
		return;
	}

	uint8_t n = 0;
	while (s[n])
		n++;
	b[0] = (uint8_t)(2 + n * 2);
	b[1] = 0x03;
	for (uint8_t i = 0; i < n; i++) {
		b[2 + i * 2] = (uint8_t)s[i];
		b[3 + i * 2] = 0;
	}
	ctrl_send(b, b[0]);
}

static void handle_setup(void)
{
	memcpy(&setup, ep0_out, sizeof(setup));
	USB_EPINTFLAG(0) = EPINT_RXSTP | EPINT_TRCPT0 | EPINT_TRCPT1;

	uint8_t kind = setup.bmRequestType & 0x60u;

	if (kind == 0x00) {
		switch (setup.bRequest) {
		case 0x06: {
			uint8_t t = setup.wValue >> 8;
			uint8_t i = setup.wValue & 0xFF;
			if (t == 0x01)
				ctrl_send(dev_desc, sizeof dev_desc);
			else if (t == 0x02)
				ctrl_send(cfg_desc, sizeof cfg_desc);
			else if (t == 0x03)
				send_string(i);
			else if (t == 0x22)
				ctrl_send(report_desc, sizeof report_desc);
			else
				ctrl_stall();
			break;
		}
		case 0x05:
			ctrl_zlp();
			USB_DADD = (1u << 7) | (setup.wValue & 0x7Fu);
			break;
		case 0x09:
			usb_config_value = setup.wValue & 0xFF;
			if (usb_config_value)
				ep1_init();
			usb_configured = usb_config_value ? 1 : 0;
			ctrl_zlp();
			break;
		case 0x08:
			ep0_in[0] = usb_config_value;
			ctrl_send(ep0_in, 1);
			break;
		case 0x00:
			ep0_in[0] = 0; ep0_in[1] = 0;
			ctrl_send(ep0_in, 2);
			break;
		case 0x0A:
		case 0x01:
		case 0x03:
			ctrl_zlp();
			break;
		case 0x0B:
			ep0_in[0] = 0;
			ctrl_send(ep0_in, 1);
			break;
		default:
			ctrl_stall();
		}
	} else if (kind == 0x20) {
		switch (setup.bRequest) {
		case 0x01:
			memset(ep0_in, 0, 8);
			ctrl_send(ep0_in, 8);
			break;
		case 0x02:
			ep0_in[0] = 0;
			ctrl_send(ep0_in, 1);
			break;
		case 0x03:
			ep0_in[0] = 1;
			ctrl_send(ep0_in, 1);
			break;
		case 0x09:
		case 0x0A:
		case 0x0B:
			ctrl_zlp();
			break;
		default:
			ctrl_stall();
		}
	} else {
		ctrl_stall();
	}

	ep_desc[0].bank[0].PCKSIZE = PCKSIZE_SIZE_64 | PCKSIZE_OUT(64);
	ep_desc[0].bank[0].STATUS_BK = 0;
	USB_EPSTATUSCLR(0) = EPSTATUS_BK0RDY;
}

static void usb_task(void)
{
	if (USB_INTFLAG & USB_INTFLAG_EORST) {
		USB_INTFLAG = USB_INTFLAG_EORST;
		USB_DADD = 0;
		usb_configured = 0;
		usb_config_value = 0;
		ep0_init();
		return;
	}

	if (USB_EPINTFLAG(0) & EPINT_RXSTP)
		handle_setup();

	if (USB_EPINTFLAG(0) & EPINT_TRCPT0) {
		USB_EPINTFLAG(0) = EPINT_TRCPT0;
		USB_EPSTATUSCLR(0) = EPSTATUS_BK0RDY;
	}
}

static void usb_init(void)
{
	PORT_PINCFG(24) = PINCFG_PMUXEN;
	PORT_PINCFG(25) = PINCFG_PMUXEN;
	PORT_PMUX(12)   = (PMUX_FUNC_G << 0) | (PMUX_FUNC_G << 4);

	USB_CTRLA = USB_CTRLA_SWRST;
	while (USB_SYNCBUSY & USB_SYNCBUSY_SWRST)
		;
	while (USB_CTRLA & USB_CTRLA_SWRST)
		;

	uint32_t cal = NVM_CAL_WORD1;
	uint32_t transn = (cal >> 13) & 0x1Fu;
	uint32_t transp = (cal >> 18) & 0x1Fu;
	uint32_t trim   = (cal >> 23) & 0x07u;
	if (transn == 0x1Fu) transn = 5;
	if (transp == 0x1Fu) transp = 29;
	if (trim   == 0x07u) trim   = 3;
	USB_PADCAL = (uint16_t)(transp | (transn << 6) | (trim << 12));

	USB_QOSCTRL  = (3u << 0) | (3u << 2);
	USB_DESCADD  = (uint32_t)&ep_desc[0];
	USB_CTRLA    = USB_CTRLA_MODE_DEV | USB_CTRLA_RUNSTDBY;
	USB_CTRLB    = USB_CTRLB_DETACH;

	USB_CTRLA |= USB_CTRLA_ENABLE;
	while (USB_SYNCBUSY & USB_SYNCBUSY_ENABLE)
		;

	ep0_init();
	USB_CTRLB &= ~USB_CTRLB_DETACH;
}

#define MOD_LSHIFT 0x02
#define MOD_LGUI   0x08
#define KEY_ENTER  0x28

static void kbd_report(uint8_t mod, uint8_t key)
{
	ep1_in[0] = mod;
	ep1_in[1] = 0;
	ep1_in[2] = key;
	ep1_in[3] = ep1_in[4] = ep1_in[5] = ep1_in[6] = ep1_in[7] = 0;

	ep_desc[1].bank[1].PCKSIZE = PCKSIZE_SIZE_8 | PCKSIZE_IN(8);
	USB_EPINTFLAG(1) = EPINT_TRCPT1;
	USB_EPSTATUSSET(1) = EPSTATUS_BK1RDY;

	uint32_t guard = 2000000u;
	while (!(USB_EPINTFLAG(1) & EPINT_TRCPT1) && guard--)
		usb_task();
}

static uint8_t ascii_to_key(char c, uint8_t *mod)
{
	*mod = 0;
	if (c >= 'a' && c <= 'z')
		return (uint8_t)(0x04 + (c - 'a'));
	if (c >= 'A' && c <= 'Z') {
		*mod = MOD_LSHIFT;
		return (uint8_t)(0x04 + (c - 'A'));
	}
	if (c >= '1' && c <= '9')
		return (uint8_t)(0x1E + (c - '1'));

	switch (c) {
	case '0': return 0x27;
	case '\n': case '\r': return KEY_ENTER;
	case '\t': return 0x2B;
	case ' ': return 0x2C;
	case '-': return 0x2D;
	case '=': return 0x2E;
	case '[': return 0x2F;
	case ']': return 0x30;
	case '\\': return 0x31;
	case ';': return 0x33;
	case '\'': return 0x34;
	case '`': return 0x35;
	case ',': return 0x36;
	case '.': return 0x37;
	case '/': return 0x38;
	case '!': *mod = MOD_LSHIFT; return 0x1E;
	case '@': *mod = MOD_LSHIFT; return 0x1F;
	case '#': *mod = MOD_LSHIFT; return 0x20;
	case '$': *mod = MOD_LSHIFT; return 0x21;
	case '%': *mod = MOD_LSHIFT; return 0x22;
	case '^': *mod = MOD_LSHIFT; return 0x23;
	case '&': *mod = MOD_LSHIFT; return 0x24;
	case '*': *mod = MOD_LSHIFT; return 0x25;
	case '(': *mod = MOD_LSHIFT; return 0x26;
	case ')': *mod = MOD_LSHIFT; return 0x27;
	case '_': *mod = MOD_LSHIFT; return 0x2D;
	case '+': *mod = MOD_LSHIFT; return 0x2E;
	case '{': *mod = MOD_LSHIFT; return 0x2F;
	case '}': *mod = MOD_LSHIFT; return 0x30;
	case '|': *mod = MOD_LSHIFT; return 0x31;
	case ':': *mod = MOD_LSHIFT; return 0x33;
	case '"': *mod = MOD_LSHIFT; return 0x34;
	case '~': *mod = MOD_LSHIFT; return 0x35;
	case '<': *mod = MOD_LSHIFT; return 0x36;
	case '>': *mod = MOD_LSHIFT; return 0x37;
	case '?': *mod = MOD_LSHIFT; return 0x38;
	}
	return 0;
}

static void type_str(const char *s)
{
	for (; *s; s++) {
		uint8_t mod, key = ascii_to_key(*s, &mod);
		if (!key)
			continue;
		kbd_report(mod, key);
		kbd_report(0, 0);
	}
}

static void run_payload(void)
{
	delay_ms(2000);

	kbd_report(MOD_LGUI, 0x15);
	kbd_report(0, 0);
	delay_ms(600);

	type_str("notepad\n");
	delay_ms(1200);

	type_str("Hello from ZeptoDuck - the world's smallest USB Rubber Ducky!\n");
}

int main(void)
{
	clock_init();
	systick_init();
	usb_init();

	while (!usb_configured)
		usb_task();

	run_payload();

	for (;;)
		usb_task();
}

extern uint32_t _sidata, _sdata, _edata, _sbss, _ebss, _estack;

void Reset_Handler(void)
{
	uint32_t *src = &_sidata;
	uint32_t *dst = &_sdata;
	while (dst < &_edata)
		*dst++ = *src++;
	for (dst = &_sbss; dst < &_ebss; )
		*dst++ = 0;

	main();
	for (;;)
		;
}

void Default_Handler(void)
{
	for (;;)
		;
}

#define ALIAS __attribute__((weak, alias("Default_Handler")))
void NMI_Handler(void)        ALIAS;
void HardFault_Handler(void)  ALIAS;
void SVC_Handler(void)        ALIAS;
void PendSV_Handler(void)     ALIAS;
void SysTick_Handler(void)    ALIAS;

__attribute__((section(".vectors"), used))
void (*const vector_table[])(void) = {
	(void (*)(void))&_estack,
	Reset_Handler,
	NMI_Handler,
	HardFault_Handler,
	0, 0, 0, 0, 0, 0, 0,
	SVC_Handler,
	0, 0,
	PendSV_Handler,
	SysTick_Handler,
	Default_Handler, Default_Handler, Default_Handler, Default_Handler,
	Default_Handler, Default_Handler, Default_Handler, Default_Handler,
	Default_Handler, Default_Handler, Default_Handler, Default_Handler,
	Default_Handler, Default_Handler, Default_Handler, Default_Handler,
	Default_Handler, Default_Handler,
};

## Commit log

2026-08-27 Created the Zeptoduck KiCad project and finished schematics
    [Zeptoduck.kicad_pcb, Zeptoduck.kicad_sch]
2026-08-27 Forgor schematics screen
2026-08-27 Add project journal entry for Day 1
    Documented the planning phase and component selection for the world's smallest Rubber Ducky project, including schematic preparation.
2026-08-27 PCB picture
2026-08-27 Update JOURNAL.md with Day 2 PCB creation details
    Documented the challenges faced while creating the PCB, including issues with component availability and manufacturing constraints.
2026-08-28 Panelization files and documenation/assets moved
    [Zeptoduck_panelized.kicad_pcb, Zeptoduck_panelized.kicad_sch]
2026-08-28 Document project progress in JOURNAL.md
    Updated the JOURNAL.md with detailed project progress, including component selection, PCB design challenges, and firmware development for the ZeptoDuck project.
2026-08-28 Updated and fixed the Panelization
    [Zeptoduck_panelized-B_Cu.gbl, Zeptoduck_panelized-B_Mask.gbs, Zeptoduck_panelized-B_Paste.gbp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]
2026-08-28 Enhance README with project details and instructions
    Expanded the README to include detailed project information, features, assembly instructions, and acknowledgments.
2026-08-28 Add BOM section to README
    Added a Bill of Materials (BOM) section with details on components and pricing.

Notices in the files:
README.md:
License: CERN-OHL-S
